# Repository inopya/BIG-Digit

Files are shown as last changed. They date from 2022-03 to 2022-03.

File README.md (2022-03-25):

# BIG Digit 7 Segmentos (3D printable)

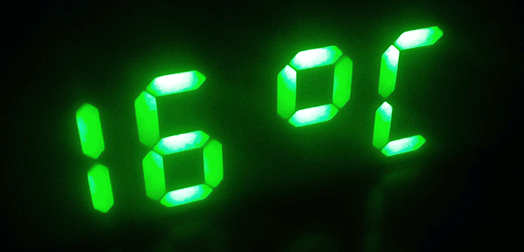
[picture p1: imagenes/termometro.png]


Display 7 segmentos para imprimir en 3D. video demo 

Permite crear digitos de 7 segmentos iluminados con tira de leds direccionable, de manera que solo necesitamos ocupar una salida del microcontrolador.

Es posible concatenar varios digitos.

En el ejemplo de la carpeta firmware se incluyen rutinas que usan hasta 4 displays y ejemplos para mostrar contadores, temperaturas y desplazamientos de mensajes de texto.

Se incluye el fichero STL. 

El tamaño de display del ejemplo esta preparado para usar tiras de leds de 144 pixels por metro 
de manera que se minimizan las soldaduras reduciendose estas solo a las conexiones entre digitos.

Se nos genera de esta manera un display de 55mm de alto por 35mm de ancho.

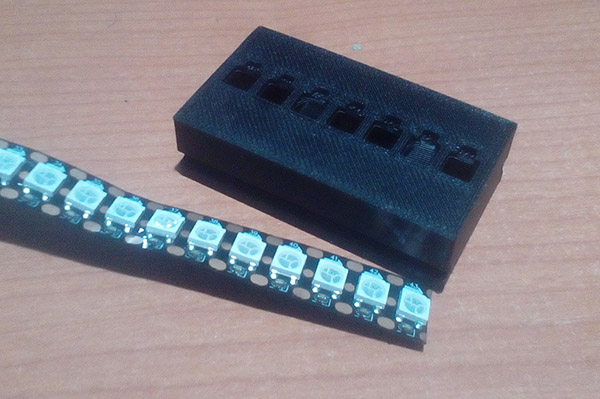
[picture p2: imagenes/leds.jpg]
  

Si se usan multiples displays el acceso a los digitos será de derecha a izquierda, es decir primero las unidades.
Dentro de cada display el orden de los segmentos es el siguiente:

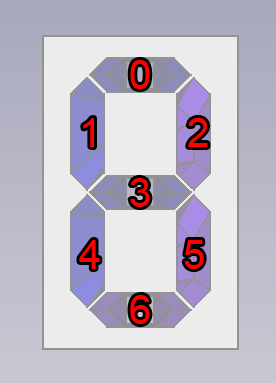
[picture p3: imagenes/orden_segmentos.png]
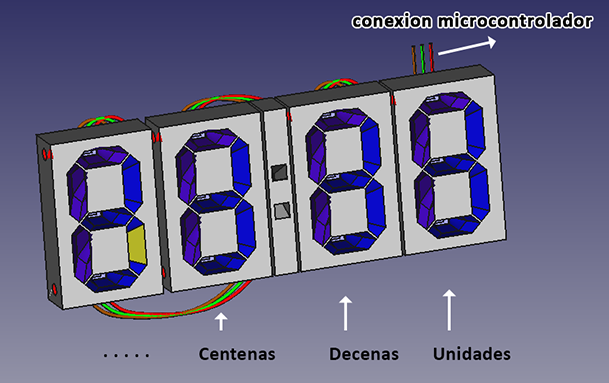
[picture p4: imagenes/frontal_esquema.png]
  

**Modelo 3D**

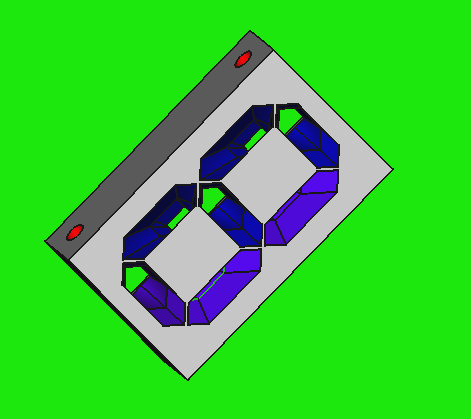
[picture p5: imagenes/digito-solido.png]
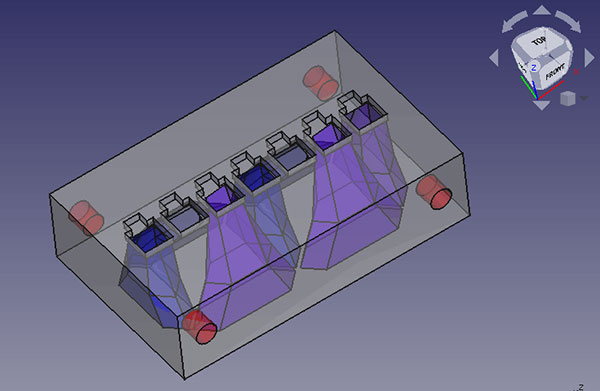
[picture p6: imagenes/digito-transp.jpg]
   

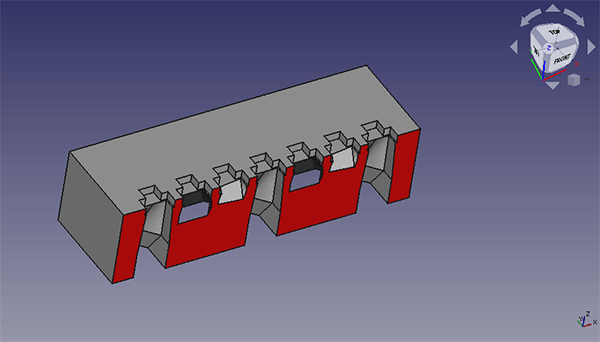
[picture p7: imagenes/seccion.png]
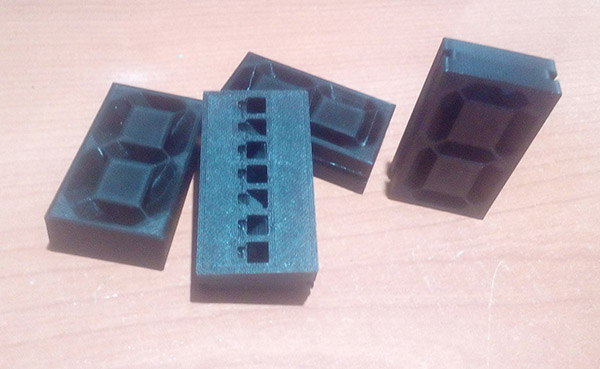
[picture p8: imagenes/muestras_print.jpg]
          

Si se imprime en la posicion que muestra la imagen se evitan los soportes 
(salvo una minima parte que corresponde a los agujeros que se usan para la union entre digitos)

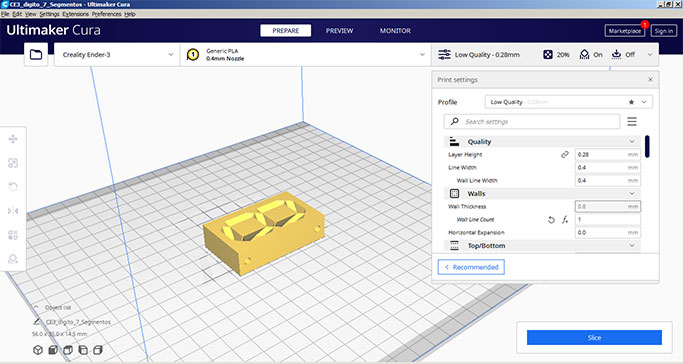
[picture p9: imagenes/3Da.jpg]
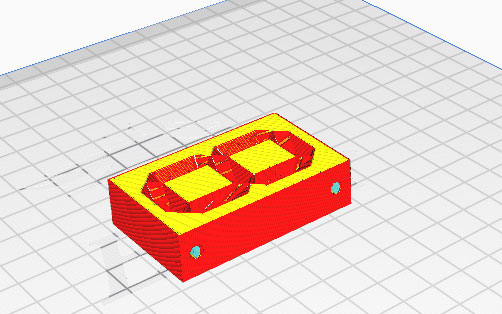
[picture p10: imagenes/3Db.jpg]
  

**Ejemplo de un reloj**

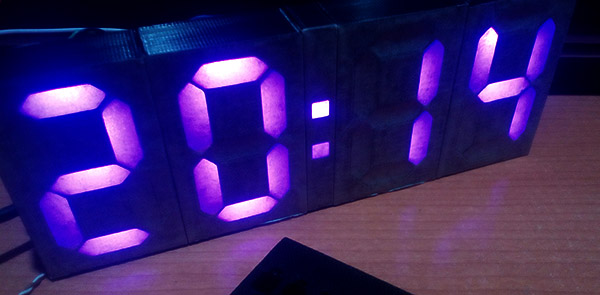
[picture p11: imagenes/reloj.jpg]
 

**Notas**

 - Si se usan simbolos especiales como es el caso de los dos puntos de separacion en el reloj de la imagen superior, 
estos deben crearse con pixeles del final de la tira leds, es decir tras la formacion de todos los digitos,
para poder mantener la compatibilidad con las funciones usadas en los ejemplos de la carpeta firmware.

 - Los digitos deberan cubrirse en su parte frontal con una lamina de un material translucido (plastico, papel, cinta de carrocero...) 
para obtener un efecto de iluminacion adecuado.

**Distribucion de los leds en el montaje del reloj...**

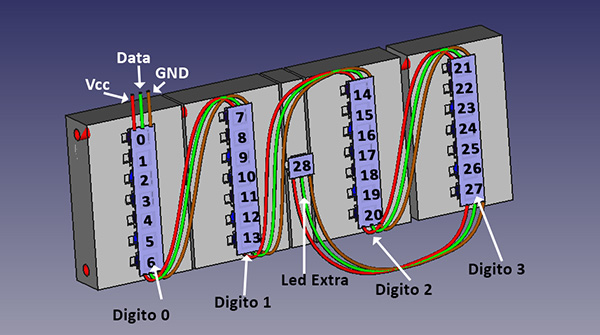
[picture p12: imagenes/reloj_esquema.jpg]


**Actualizacion...**

Añadida otra version de digito (distinta tipografía) en la carpeta "stl_v2"
Los conos de proyeccion de este modelo quedan demasiado juntos entre algunos de los segmentos y se producen "perforaciones" en dos lugares, con lo que será necesario imprimir activando "horizontal expansion" desde Ultimaker Cura, con un valor de 0.2
Queda pendiente retocar el modelo para evitar ese pequeño bug.

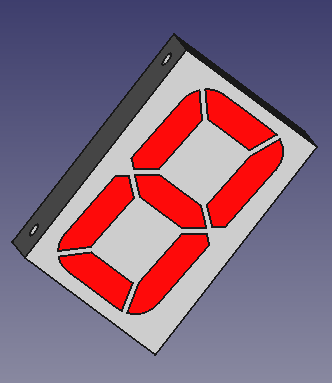
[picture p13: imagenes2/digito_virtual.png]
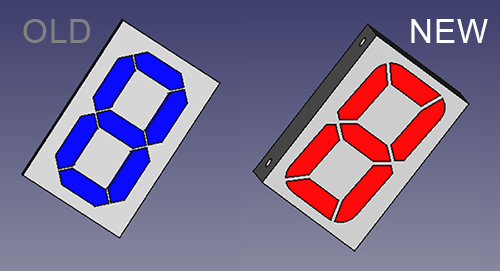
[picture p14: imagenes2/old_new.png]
        

Detalle del modelo sin y con "horizontal expansion"

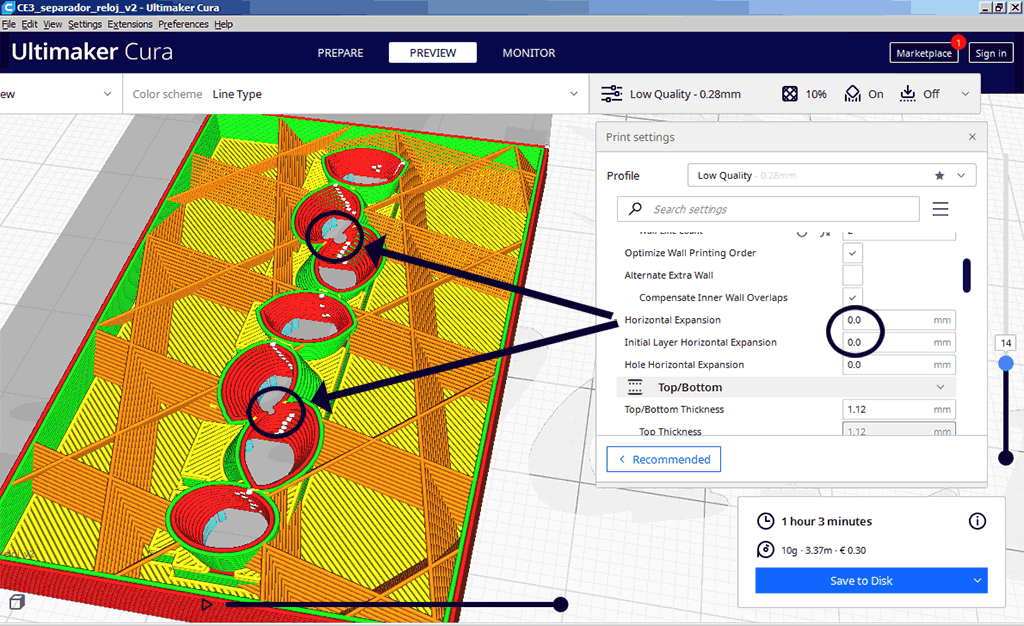
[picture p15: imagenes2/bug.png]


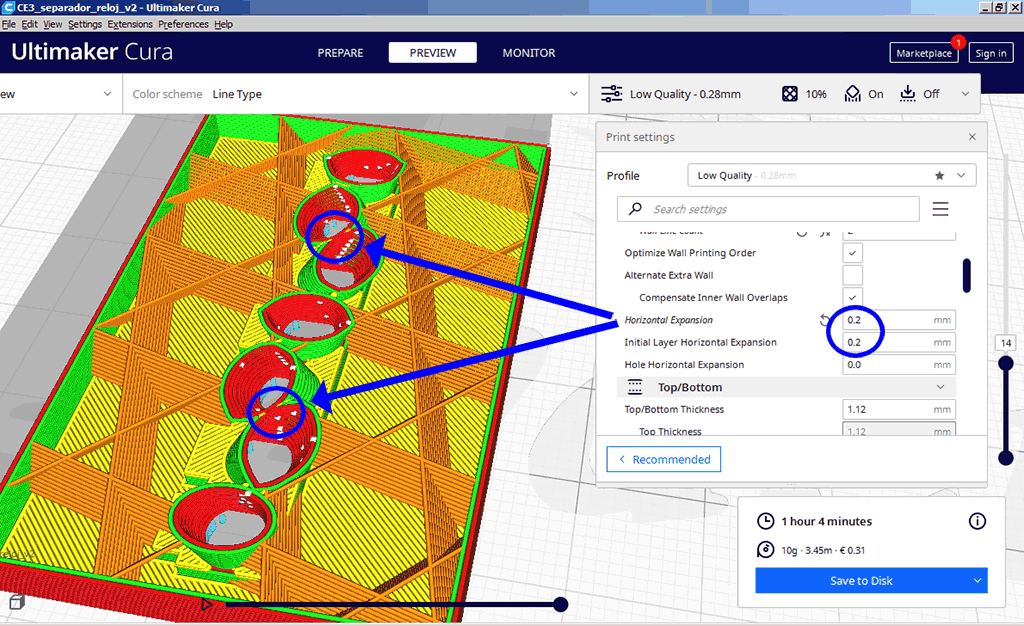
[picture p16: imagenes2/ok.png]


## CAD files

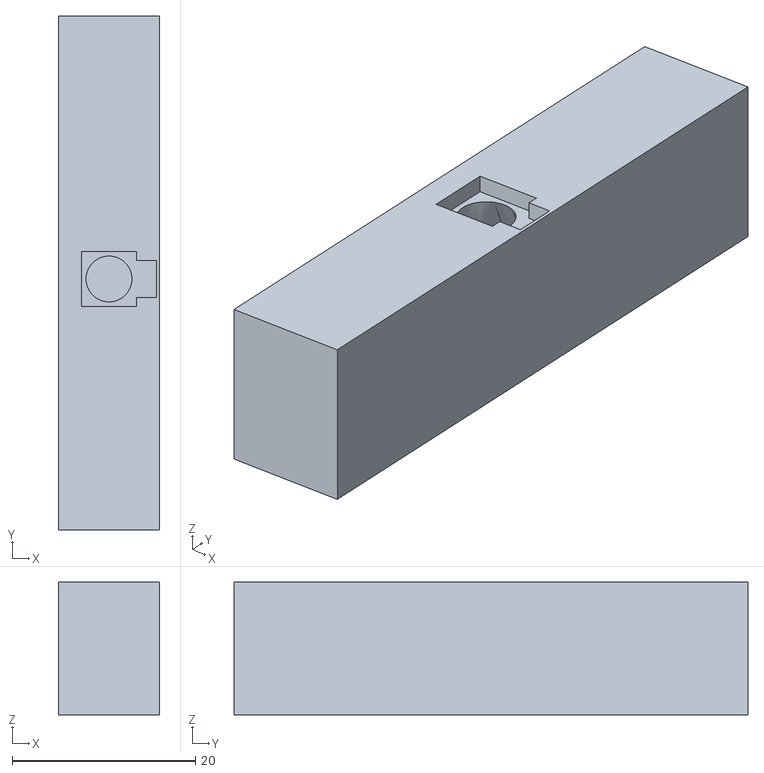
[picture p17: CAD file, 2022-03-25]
stl_v2/separador_reloj_v2.stl
11.0 x 56.0 x 14.5

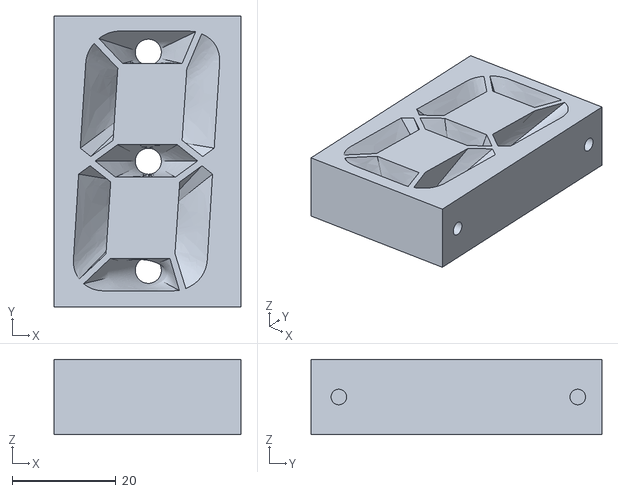
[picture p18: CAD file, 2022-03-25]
stl_v2/digito_v2.stl
36.0 x 56.0 x 14.5

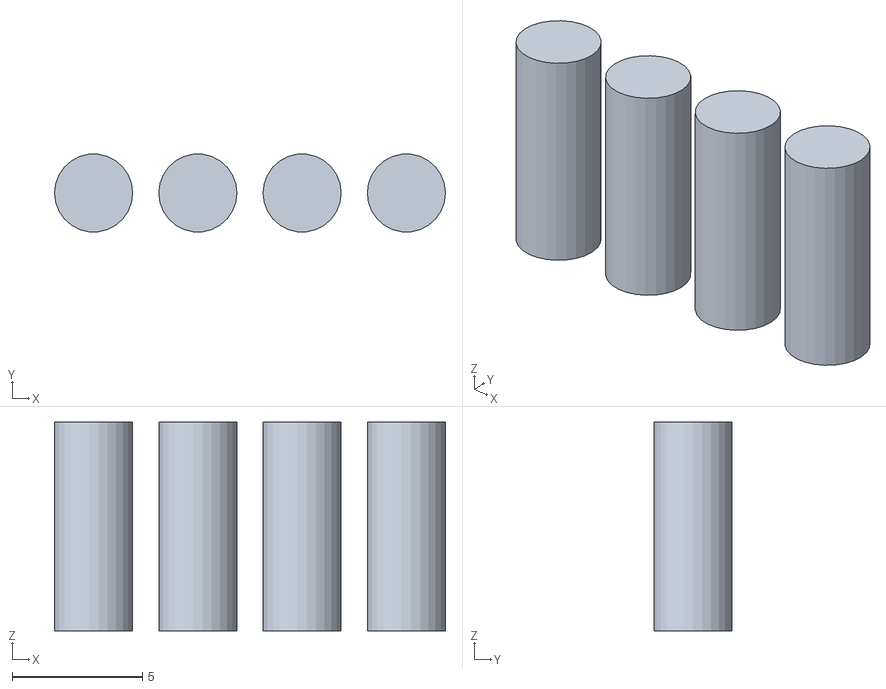
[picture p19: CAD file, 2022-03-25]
stl_v2/union_digitos_v2.stl
15.0 x 2.98 x 8.00

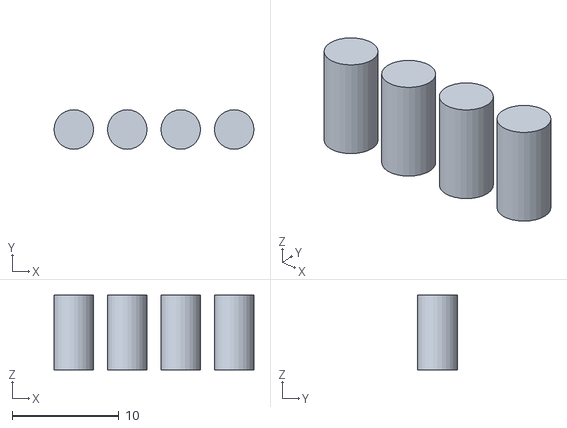
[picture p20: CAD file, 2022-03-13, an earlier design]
stl/union_digitos.stl
18.7 x 3.70 x 7.00

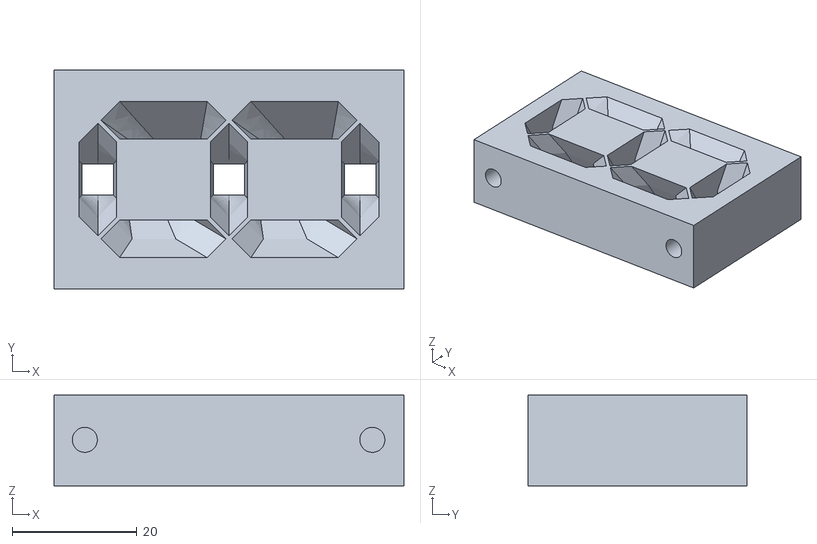
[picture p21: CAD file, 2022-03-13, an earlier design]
stl/digito_7_Segmentos.stl
56.0 x 35.0 x 14.5

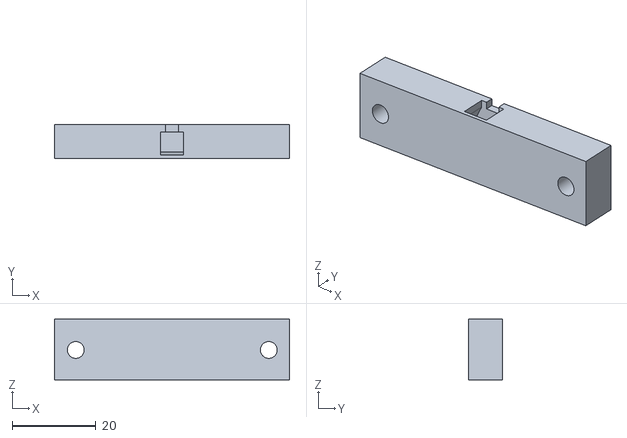
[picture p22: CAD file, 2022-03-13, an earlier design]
stl/Separador_reloj.stl
56.0 x 8.00 x 14.5

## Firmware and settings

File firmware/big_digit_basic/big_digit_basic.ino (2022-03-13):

/*
#       _\|/_   A ver..., ¿que tenemos por aqui?
#       (O-O)        
# ---oOO-(_)-OOo---------------------------------
 
 
##########################################################
# ****************************************************** #
# *           DOMOTICA PARA PRINCIPIANTES              * #
# *                  BIG DIGIT 2022                    * #
# *          Autor:  Eulogio López Cayuela             * #
# *                                                    * #
# *       Versión 1.0        Fecha: 28/02/2022         * #
# ****************************************************** #
##########################################################
*/





//------------------------------------------------------
//Importamos las librerias necesarias
//------------------------------------------------------


#include  <Arduino.h>				        //compatibilidad con entorno ARDUINO en platformio


#include <Adafruit_NeoPixel.h>      // Incluir biblioteca Adafruit NeoPixel

//ficheros personales 
#include "definiciones.h"
#include "pinout.h"
#include "variables.h"
#include "led_strip.h"




/*mmmmmmmmmmmmmmmmmmmmmmmmmmmmmmmmmmmmmmmmmmmmmmmmmmmmmmmmmmmmmmmmmmmmmmmmmmmmmmmmmmmmmmmmmmmmmmmmmmm
//   Prototipado de  funciones
//mmmmmmmmmmmmmmmmmmmmmmmmmmmmmmmmmmmmmmmmmmmmmmmmmmmmmmmmmmmmmmmmmmmmmmmmmmmmmmmmmmmmmmmmmmmmmmmmmmm*/


void bigDigit_NUM( uint8_t pos ,uint8_t numero, uint8_t _red, uint8_t _green, uint8_t _blue );
void bigDigit_TXT( uint8_t pos ,uint8_t _caracter, uint8_t _red, uint8_t _green, uint8_t _blue );
void bigCifra( uint16_t cifra, uint8_t _red, uint8_t _green, uint8_t _blue );
void borrarDisplay( void );
void rotuloRotativoPuntero(uint8_t *mensaje, int8_t LM, int8_t sentido, uint8_t _r, uint8_t _g, uint8_t _b, uint16_t _pause);


float read_NTC( void ); 


void contador( void );
void mostrar_mensaje( void );
void termometro_color( void );



/*mmmmmmmmmmmmmmmmmmmmmmmmmmmmmmmmmmmmmmmmmmmmmmmmmmmmmmmmmmmmmmmmmmmmmmmmmmmmmmmmmmmmmmmmmmmmmmmmmmmmmmmm
   ****************************************************************************************************** 
                                    FUNCION DE CONFIGURACION
   ****************************************************************************************************** 
//mmmmmmmmmmmmmmmmmmmmmmmmmmmmmmmmmmmmmmmmmmmmmmmmmmmmmmmmmmmmmmmmmmmmmmmmmmmmmmmmmmmmmmmmmmmmmmmmmmmmmmmm*/

void setup()
{
  
  pinMode(PIN_LED_OnBoard, OUTPUT);
  digitalWrite(PIN_LED_OnBoard, LED_ON);

  pinMode(PIN_TIRA_LED, OUTPUT);  // pin para la linea DATA de los leds
  tiraLEDS.begin();               // Initializar el objeto 'tiraLEDS'
  
  /* establecer la cantidad de brillo */
  tiraLEDS.setBrightness(25);
  tiraLEDS.clear();
  tiraLEDS.show();



  digitalWrite(PIN_LED_OnBoard, LED_OFF);     



}




/*mmmmmmmmmmmmmmmmmmmmmmmmmmmmmmmmmmmmmmmmmmmmmmmmmmmmmmmmmmmmmmmmmmmmmmmmmmmmmmmmmmmmmmmmmmmmmmmmmmmmmmmm
   ****************************************************************************************************** 
                                  BUCLE PRINCIPAL DEL PROGRAMA
   ****************************************************************************************************** 
//mmmmmmmmmmmmmmmmmmmmmmmmmmmmmmmmmmmmmmmmmmmmmmmmmmmmmmmmmmmmmmmmmmmmmmmmmmmmmmmmmmmmmmmmmmmmmmmmmmmmmmmm*/

 
void loop()
{
    
contador();
mostrar_mensaje();
termometro_color();
}




/*mmmmmmmmmmmmmmmmmmmmmmmmmmmmmmmmmmmmmmmmmmmmmmmmmmmmmmmmmmmmmmmmmmmmmmmmmmmmmmmmmmmmmmmmmmmmmmmmmmm
//   FUNCIONES DE CONTROL BASICO DEL DISPLAY  (CONTROL DE LA TIRA DE LEDS)
//mmmmmmmmmmmmmmmmmmmmmmmmmmmmmmmmmmmmmmmmmmmmmmmmmmmmmmmmmmmmmmmmmmmmmmmmmmmmmmmmmmmmmmmmmmmmmmmmmmm*/

//========================================================
//    BORRAR DISPLAY
//========================================================

 
void borrarDisplay()
{
  tiraLEDS.clear();
}


//========================================================
//    CREAR DIGITOS NUMERICOS
//========================================================

void bigDigit_NUM(uint8_t pos ,uint8_t numero, uint8_t _red, uint8_t _green, uint8_t _blue)
{
  //buscalos numeros sobre una lista, ideal apra resultados de operaciones numericas
  for (int pixel=0; pixel< 7; pixel++){  // recorremos la matrid de segmentos para formar el numero
    //la matriz de segmentos indica si los led se apagan o encienden
    if (numero>11) { numero=numero%10; }  //evitar que cifras grandes desborden
    if (getBit(numeros[numero],pixel) == 1) { //encender el segmento
      tiraLEDS.setPixelColor(pixel+pos*7, tiraLEDS.Color(_red, _green, _blue)); //color unico
    }
    else { tiraLEDS.setPixelColor(pixel+pos*7, 0); }   
  }
  tiraLEDS.show(); //pasar la informaciona los led
}  



//========================================================
//    CREAR CARACTERES GENERICOS TEXTO, NUMERO Y SIMBOLOS
//========================================================

void bigDigit_TXT(uint8_t pos ,uint8_t _caracter, uint8_t _red, uint8_t _green, uint8_t _blue)
{
  for (int pixel=0; pixel< 7; pixel++){  // recorremos la matrid de segmentos para formar el numero
    //la matriz de segmentos indica si los led se apagan o encienden
    if (getBit(_caracter,pixel) == 1) { //encender el segmento
      tiraLEDS.setPixelColor(pixel+pos*7, tiraLEDS.Color(_red, _green, _blue)); //color unico
    }
    else { tiraLEDS.setPixelColor(pixel+pos*7, 0); }   
  }
  tiraLEDS.show(); //pasar la informaciona los led
} 


//========================================================
//    CREAR CIFRAS QUE OCUPAN TODO EL DISPLAY (NUMEROS O-9999)
//========================================================

void bigCifra(uint16_t cifra, uint8_t _red, uint8_t _green, uint8_t _blue)
{
  uint8_t unidades = cifra%10;
  uint8_t decenas  = (cifra/10)%10;
  uint8_t centenas = (cifra/100)%10;
  uint8_t millares = (cifra/1000)%10; 
  bigDigit_NUM(3, millares, _red, _green, _blue);
  bigDigit_NUM(2, centenas, _red, _green, _blue);
  bigDigit_NUM(1, decenas,  _red, _green, _blue);
  bigDigit_NUM(0, unidades, _red, _green, _blue);
}  

//========================================================
//    ROTULO ROTATIVO PUNTEROS
//========================================================

void rotuloRotativoPuntero(uint8_t *mensaje, int8_t LM, int8_t sentido, uint8_t _r, uint8_t _g, uint8_t _b, uint16_t _pause)
{
  borrarDisplay();

  const uint8_t DISPLAY_SIZE = 4;
  const uint8_t EXTRA_ESPACES = 0;  //Espacios añadidos tras el mensaje.
                                    //crean un retraso en la repeticion del mensaje


  int8_t pos;

  if (sentido>0)   pos = LM+ DISPLAY_SIZE + EXTRA_ESPACES; //derecha
  else pos = (-1) * DISPLAY_SIZE;
 

  while(true){
    if (sentido>0) { //derecha
      for(int8_t offset=DISPLAY_SIZE-1;offset>=0;offset--){
      if ((pos-offset)>=0 && (pos-offset)<LM) {bigDigit_TXT( offset, mensaje[pos-offset]  , _r, _g, _b ); }
      else{bigDigit_TXT( offset, CARACTER_OFF  , COLOR_NEGRO ); }
      }  
      pos--;
      if( pos <-1 ) { return; } 
    }  
    else{ //izquierda
      for(int8_t offset=0;offset<DISPLAY_SIZE;offset++){
        if ((pos-offset)>=0 && (pos-offset)<LM) {bigDigit_TXT( offset, mensaje[pos-offset]  , _r, _g, _b ); }
        else{ bigDigit_TXT( offset, CARACTER_OFF  , COLOR_NEGRO ); }
      }    
      pos++;
      if( pos >= (LM + DISPLAY_SIZE + EXTRA_ESPACES) ) { return; } 
    }
    delay(_pause);    
   
  }
}

/*mmmmmmmmmmmmmmmmmmmmmmmmmmmmmmmmmmmmmmmmmmmmmmmmmmmmmmmmmmmmmmmmmmmmmmmmmmmmmmmmmmmmmmmmmmmmmmmmmmmmmmmm
//    SENSOR NTC  
//mmmmmmmmmmmmmmmmmmmmmmmmmmmmmmmmmmmmmmmmmmmmmmmmmmmmmmmmmmmmmmmmmmmmmmmmmmmmmmmmmmmmmmmmmmmmmmmmmmmmmmmm*/

float read_NTC() 
{
  const int Rc = 10000;       //valor de la resistencia
  float K = 2.5;              //factor de disipacion en mW/C
  float A = 1.11492089e-3;
  float B = 2.372075385e-4;
  float C = 6.954079529e-8;
  
  float ERROR_NTC = 1.128;//1.128-1.132

  //------------------------------//
  
  float raw = analogRead(PIN_sensorNTC);

  float Vcc = 3.3; 
  float V =  raw / 1023 * Vcc;
  
  float R = (Rc * V ) / (Vcc - V);
  
 
  float logR  = log(R);
  float R_th = 1.0 / (A + B * logR + C * logR * logR * logR );
 
  float kelvin = R_th - V*V/(K * R)*1000;
  float celsius = kelvin - 273.15;

  return celsius*ERROR_NTC;

}




/*mmmmmmmmmmmmmmmmmmmmmmmmmmmmmmmmmmmmmmmmmmmmmmmmmmmmmmmmmmmmmmmmmmmmmmmmmmmmmmmmmmmmmmmmmmmmmmmmmmm
//   OTRAS FUNCIONES DEL DISPLAY
//mmmmmmmmmmmmmmmmmmmmmmmmmmmmmmmmmmmmmmmmmmmmmmmmmmmmmmmmmmmmmmmmmmmmmmmmmmmmmmmmmmmmmmmmmmmmmmmmmmm*/


//========================================================
//    TERMOMETRO COLOR SEGUN TEMPERATURA
//========================================================

void termometro_color()
{
  float temperatura = read_NTC();
  uint8_t unidades = int(temperatura)%10;
  uint8_t decenas = int(temperatura)/10; 

  if(temperatura<15){
    bigDigit_NUM(3, decenas,  COLOR_AZUL);
    bigDigit_NUM(2, unidades, COLOR_AZUL); 
    bigDigit_TXT(1 ,CARACTER_GRADO, COLOR_AZUL);       
    bigDigit_TXT(0 ,CARACTER_C, COLOR_AZUL);
  }
  else if(temperatura>24){
    bigDigit_NUM(3, decenas,  COLOR_ROJO);
    bigDigit_NUM(2, unidades, COLOR_ROJO);
    bigDigit_TXT(1 ,CARACTER_GRADO, COLOR_ROJO);        
    bigDigit_TXT(0 ,CARACTER_C, COLOR_ROJO);
  }
  else{
    bigDigit_NUM(3, decenas,  COLOR_VERDE);
    bigDigit_NUM(2, unidades, COLOR_VERDE);        
    bigDigit_TXT(1 ,CARACTER_GRADO, COLOR_VERDE);
    bigDigit_TXT(0 ,CARACTER_C, COLOR_VERDE);
  }

}

//========================================================
//    CONTADOR
//========================================================

void contador()
{

  for (uint16_t numero=0;numero<10000;numero++){
      bigCifra(numero, 255, 0, 0 );
      delay(100); 
  }
  

}


//========================================================
//    MOSTRAR MENSAJE
//========================================================

void mostrar_mensaje()
{
    
    uint8_t mensaje [] = {  
                          CARACTER_E , CARACTER_r , CARACTER_r , CARACTER_o , CARACTER_r, 
                          CARACTER_OFF, CARACTER_c, CARACTER_o, CARACTER_d, CARACTER_E,
                          CARACTER_OFF, CARACTER_4, CARACTER_0, CARACTER_4,
                         } ;

  rotuloRotativoPuntero(mensaje, sizeof(mensaje)/sizeof(mensaje[0]), 0, COLOR_VERDE, 250);


}








//*******************************************************
//                    FIN DE PROGRAMA
//*******************************************************
